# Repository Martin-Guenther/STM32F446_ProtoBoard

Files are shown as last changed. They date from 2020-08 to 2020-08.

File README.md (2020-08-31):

# STM32F446_ProtoBoard
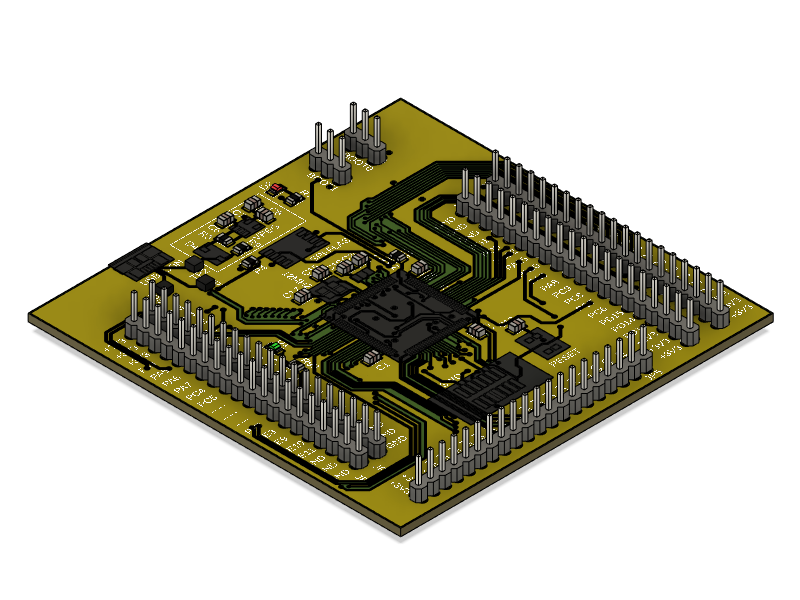
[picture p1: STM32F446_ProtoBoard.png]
STM32F446_ProtoBoard

  
A minimalist board with an STM32F446 microcontroller that can be used for prototypes. Most pins of the chip are routed to headers. It is powered over a USB connector and can also act as a USB device. It has SPI flash memory included and must be programmed via SWD.

### License
This is Open-Source-Hardware released under the GNU GPL license.

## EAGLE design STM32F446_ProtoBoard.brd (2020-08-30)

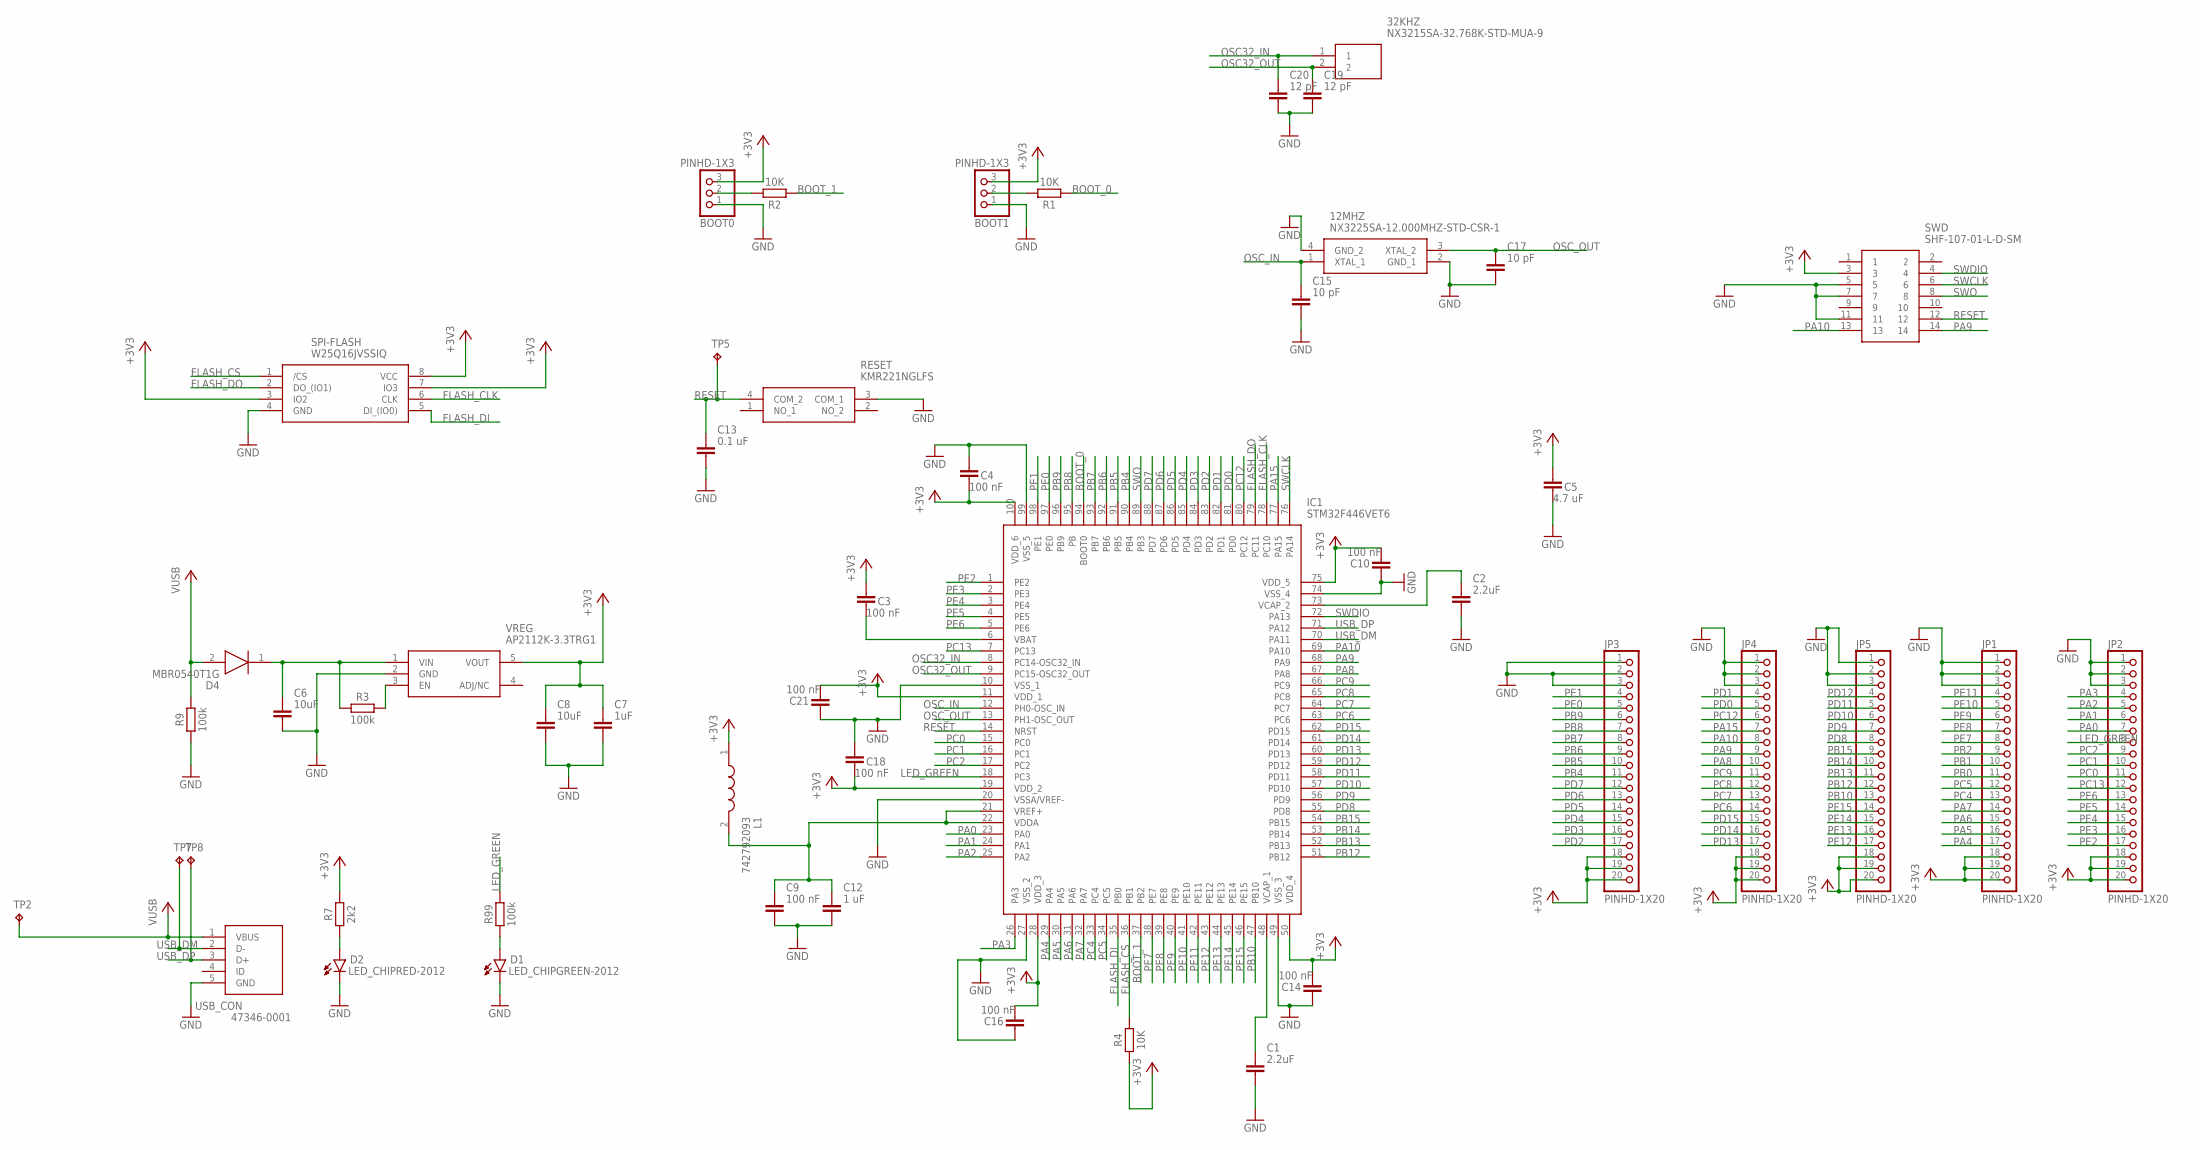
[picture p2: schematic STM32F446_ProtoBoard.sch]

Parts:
12MHZ: NX3225SA-12.000MHZ-STD-CSR-1; NX3225SA12000MHZSTDCSR1
32KHZ: NX3215SA-32.768K-STD-MUA-9; NX3215SA
BOOT0, BOOT1: PINHD-1X3; 1X03
C1, C2: 2.2uF; CAPC2012X110
C3, C4, C9, C10, C14, C16, C18, C21: 100 nF; CAPC2012X110
C5: 4.7 uF; CAPC2012X110
C6, C8: 10uF; CAPC2012X110
C7: 1uF; CAPC2012X110
C12: 1 uF; CAPC2012X110
C13: 0.1 uF; CAPC2012X110
C15, C17: 10 pF; CAPC2012X110
C19, C20: 12 pF; CAPC2012X110
D1: LED_CHIPGREEN-2012; LEDC2012X110N_G
D2: LED_CHIPRED-2012; LEDC2012X110N_R
D4: MBR0540T1G; SOD3716X135N
IC1: STM32F446VET6; QFP50P1600X1600X160-100N
JP1, JP2, JP3, JP4, JP5: PINHD-1X20; 1X20
L1: 742792093; CAPC2012X110N
R1, R2, R4: 10K; RESC2012X65
R3, R9, R99: 100k; RESC2012X65
R7: 2k2; RESC2012X65
RESET: KMR221NGLFS
SPI-FLASH: W25Q16JVSSIQ; SOIC127P790X216-8N
SWD: SHF-107-01-L-D-SM; SHF-107-01-X-D-SM
TP2, TP5, TP7, TP8: TPTP20R; TP20R
USB_CON: 47346-0001
VREG: AP2112K-3.3TRG1; SOT95P282X130-5N

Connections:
+3V3: BOOT0.3, BOOT1.3, C3.1, C4.2, C5.1, C7.1, C8.1, C10.2, C14.2, C16.2, C18.2, C21.2, IC1.11 (VDD_1), IC1.19 (VDD_2), IC1.28 (VDD_3), IC1.50 (VDD_4), IC1.75 (VDD_5), IC1.100 (VDD_6), JP1.18, JP1.19, JP1.20, JP2.18, JP2.19, JP2.20, JP3.18, JP3.19, JP3.20, JP4.18, JP4.19, JP4.20, JP5.18, JP5.19, JP5.20, L1.1, R4.1, R7.2, SPI-FLASH.3 (IO2), SPI-FLASH.7 (IO3), SPI-FLASH.8 (VCC), SWD.3, VREG.5 (VOUT)
+5V: D4.2 (A), R9.2, TP2.TP, USB_CON.1 (VBUS)
BOOT_0: IC1.94 (BOOT0), R1.1
BOOT_1: IC1.37 (PB2), R2.1
FLASH_CLK: IC1.78 (PC10), SPI-FLASH.6 (CLK)
FLASH_CS: IC1.36 (PB1), R4.2, SPI-FLASH.1 (/CS)
FLASH_DI: IC1.35 (PB0), SPI-FLASH.5 (DI_(IO0))
FLASH_DO: IC1.79 (PC11), SPI-FLASH.2 (DO_(IO1))
GND: 12MHZ.2 (GND_1), 12MHZ.4 (GND_2), BOOT0.1, BOOT1.1, C1.2, C2.2, C4.1, C5.2, C6.2, C7.2, C8.2, C9.2, C10.1, C12.2, C13.2, C14.1, C15.2, C16.1, C17.2, C18.1, C19.2, C20.2, C21.1, D1.1 (C), D2.1 (C), IC1.10 (VSS_1), IC1.20 (VSSA/VREF-), IC1.27 (VSS_2), IC1.49 (VSS_3), IC1.74 (VSS_4), IC1.99 (VSS_5), JP1.1, JP1.2, JP1.3, JP2.1, JP2.2, JP2.3, JP3.1, JP3.2, JP3.3, JP4.1, JP4.2, JP4.3, JP5.1, JP5.2, JP5.3, R9.1, RESET.3 (COM_1), SPI-FLASH.4 (GND), SWD.5, SWD.7, SWD.11, USB_CON.5 (GND), VREG.2 (GND)
LED_GREEN: IC1.18 (PC3), JP2.8, R99.2
unnamed: C6.1, D4.1 (K), R3.1, VREG.1 (VIN)
unnamed: R3.2, VREG.3 (EN)
unnamed: D2.2 (A), R7.1
unnamed: D1.2 (A), R99.1
unnamed: C1.1, IC1.48 (VCAP_1)
unnamed: C3.2, IC1.6 (VBAT)
unnamed: BOOT1.2, R1.2
unnamed: C2.1, IC1.73 (VCAP_2)
unnamed: BOOT0.2, R2.2
unnamed: C9.1, C12.1, IC1.21 (VREF+), IC1.22 (VDDA), L1.2
OSC32_IN: 32KHZ.1, C20.1, IC1.8 (PC14-OSC32_IN)
OSC32_OUT: 32KHZ.2, C19.1, IC1.9 (PC15-OSC32_OUT)
OSC_IN: 12MHZ.1 (XTAL_1), C15.1, IC1.12 (PH0-OSC_IN)
OSC_OUT: 12MHZ.3 (XTAL_2), C17.1, IC1.13 (PH1-OSC_OUT)
PA0: IC1.23 (PA0), JP2.7
PA1: IC1.24 (PA1), JP2.6
PA2: IC1.25 (PA2), JP2.5
PA3: IC1.26 (PA3), JP2.4
PA4: IC1.29 (PA4), JP1.17
PA5: IC1.30 (PA5), JP1.16
PA6: IC1.31 (PA6), JP1.15
PA7: IC1.32 (PA7), JP1.14
PA8: IC1.67 (PA8), JP4.10
PA9: IC1.68 (PA9), JP4.9, SWD.14
PA10: IC1.69 (PA10), JP4.8, SWD.13
PA15: IC1.77 (PA15), JP4.7
PB0: JP1.11
PB1: JP1.10
PB2: JP1.9
PB4: IC1.90 (PB4), JP3.11
PB5: IC1.91 (PB5), JP3.10
PB6: IC1.92 (PB6), JP3.9
PB7: IC1.93 (PB7), JP3.8
PB8: IC1.95 (PB), JP3.7
PB9: IC1.96 (PB9), JP3.6
PB10: IC1.47 (PB10), JP5.13
PB12: IC1.51 (PB12), JP5.12
PB13: IC1.52 (PB13), JP5.11
PB14: IC1.53 (PB14), JP5.10
PB15: IC1.54 (PB15), JP5.9
PC0: IC1.15 (PC0), JP2.11
PC1: IC1.16 (PC1), JP2.10
PC2: IC1.17 (PC2), JP2.9
PC4: IC1.33 (PC4), JP1.13
PC5: IC1.34 (PC5), JP1.12
PC6: IC1.63 (PC6), JP4.14
PC7: IC1.64 (PC7), JP4.13
PC8: IC1.65 (PC8), JP4.12
PC9: IC1.66 (PC9), JP4.11
PC12: IC1.80 (PC12), JP4.6
PC13: IC1.7 (PC13), JP2.12
PD0: IC1.81 (PD0), JP4.5
PD1: IC1.82 (PD1), JP4.4
PD2: IC1.83 (PD2), JP3.17
PD3: IC1.84 (PD3), JP3.16
PD4: IC1.85 (PD4), JP3.15
PD5: IC1.86 (PD5), JP3.14
PD6: IC1.87 (PD6), JP3.13
PD7: IC1.88 (PD7), JP3.12
PD8: IC1.55 (PD8), JP5.8
PD9: IC1.56 (PD9), JP5.7
PD10: IC1.57 (PD10), JP5.6
PD11: IC1.58 (PD11), JP5.5
PD12: IC1.59 (PD12), JP5.4
PD13: IC1.60 (PD13), JP4.17
PD14: IC1.61 (PD14), JP4.16
PD15: IC1.62 (PD15), JP4.15
PE0: IC1.97 (PE0), JP3.5
PE1: IC1.98 (PE1), JP3.4
PE2: IC1.1 (PE2), JP2.17
PE3: IC1.2 (PE3), JP2.16
PE4: IC1.3 (PE4), JP2.15
PE5: IC1.4 (PE5), JP2.14
PE6: IC1.5 (PE6), JP2.13
PE7: IC1.38 (PE7), JP1.8
PE8: IC1.39 (PE8), JP1.7
PE9: IC1.40 (PE9), JP1.6
PE10: IC1.41 (PE10), JP1.5
PE11: IC1.42 (PE11), JP1.4
PE12: IC1.43 (PE12), JP5.17
PE13: IC1.44 (PE13), JP5.16
PE14: IC1.45 (PE14), JP5.15
PE15: IC1.46 (PE15), JP5.14
RESET: C13.1, IC1.14 (NRST), RESET.4 (COM_2), SWD.12, TP5.TP
SWCLK: IC1.76 (PA14), SWD.6
SWDIO: IC1.72 (PA13), SWD.4
SWO: IC1.89 (PB3), SWD.8
USB_DM: IC1.70 (PA11), TP7.TP, USB_CON.2 (D-)
USB_DP: IC1.71 (PA12), TP8.TP, USB_CON.3 (D+)

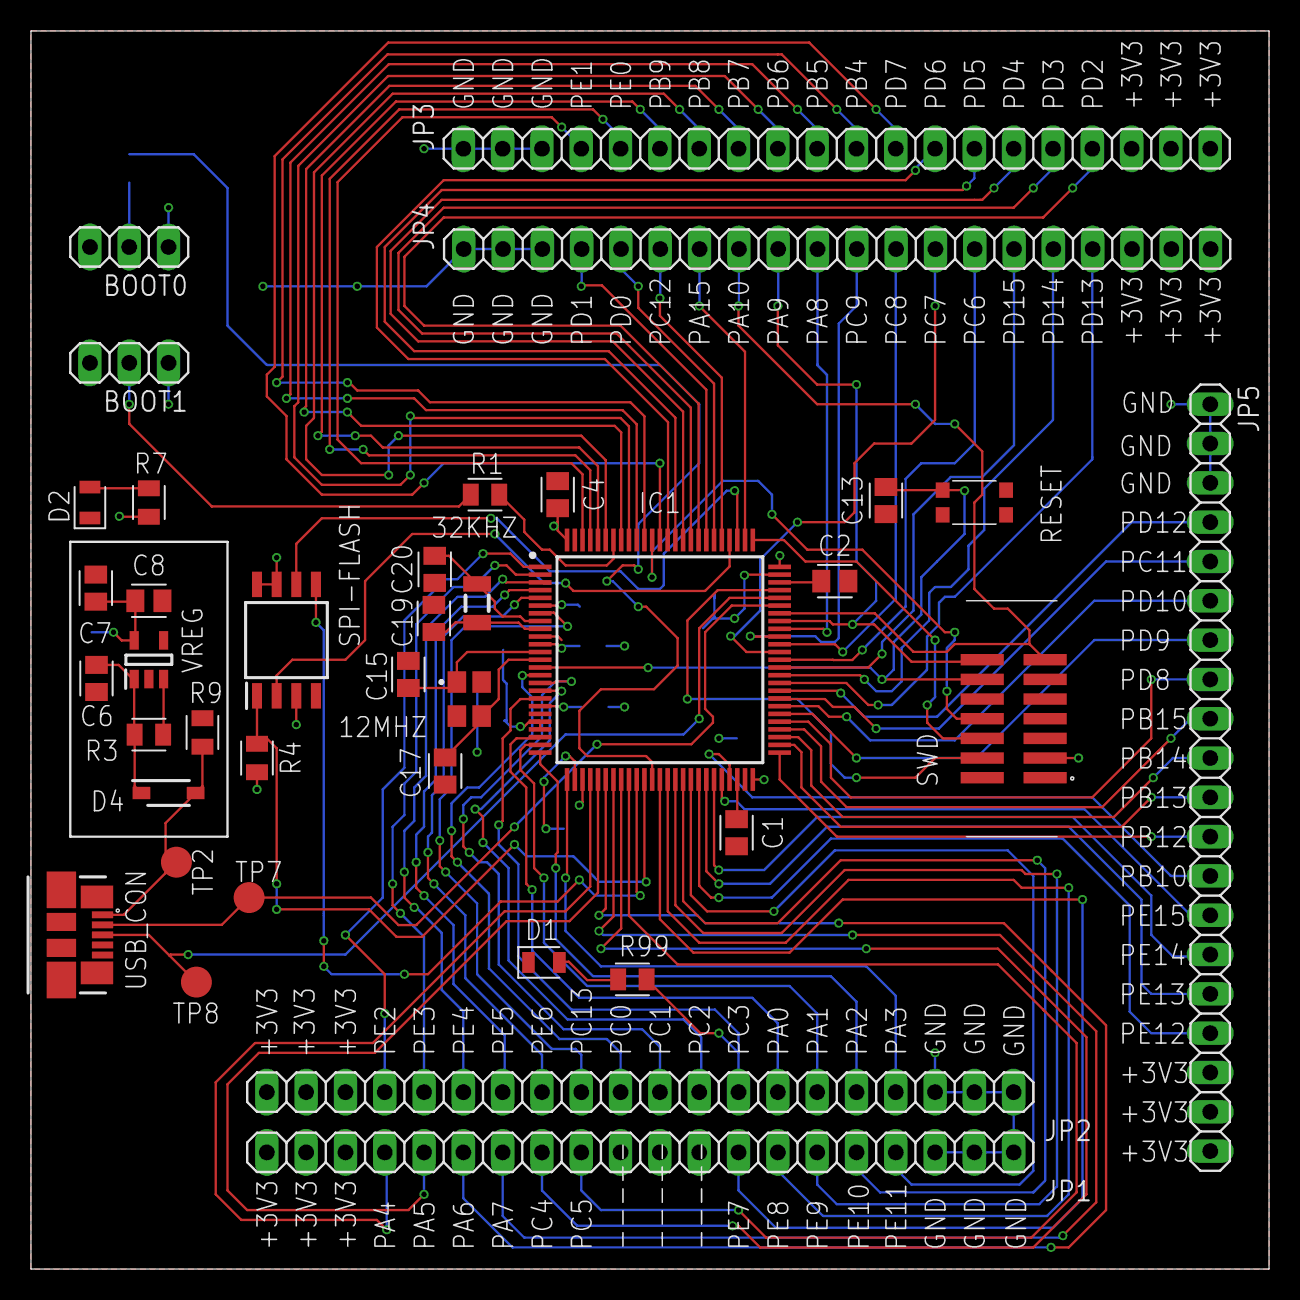
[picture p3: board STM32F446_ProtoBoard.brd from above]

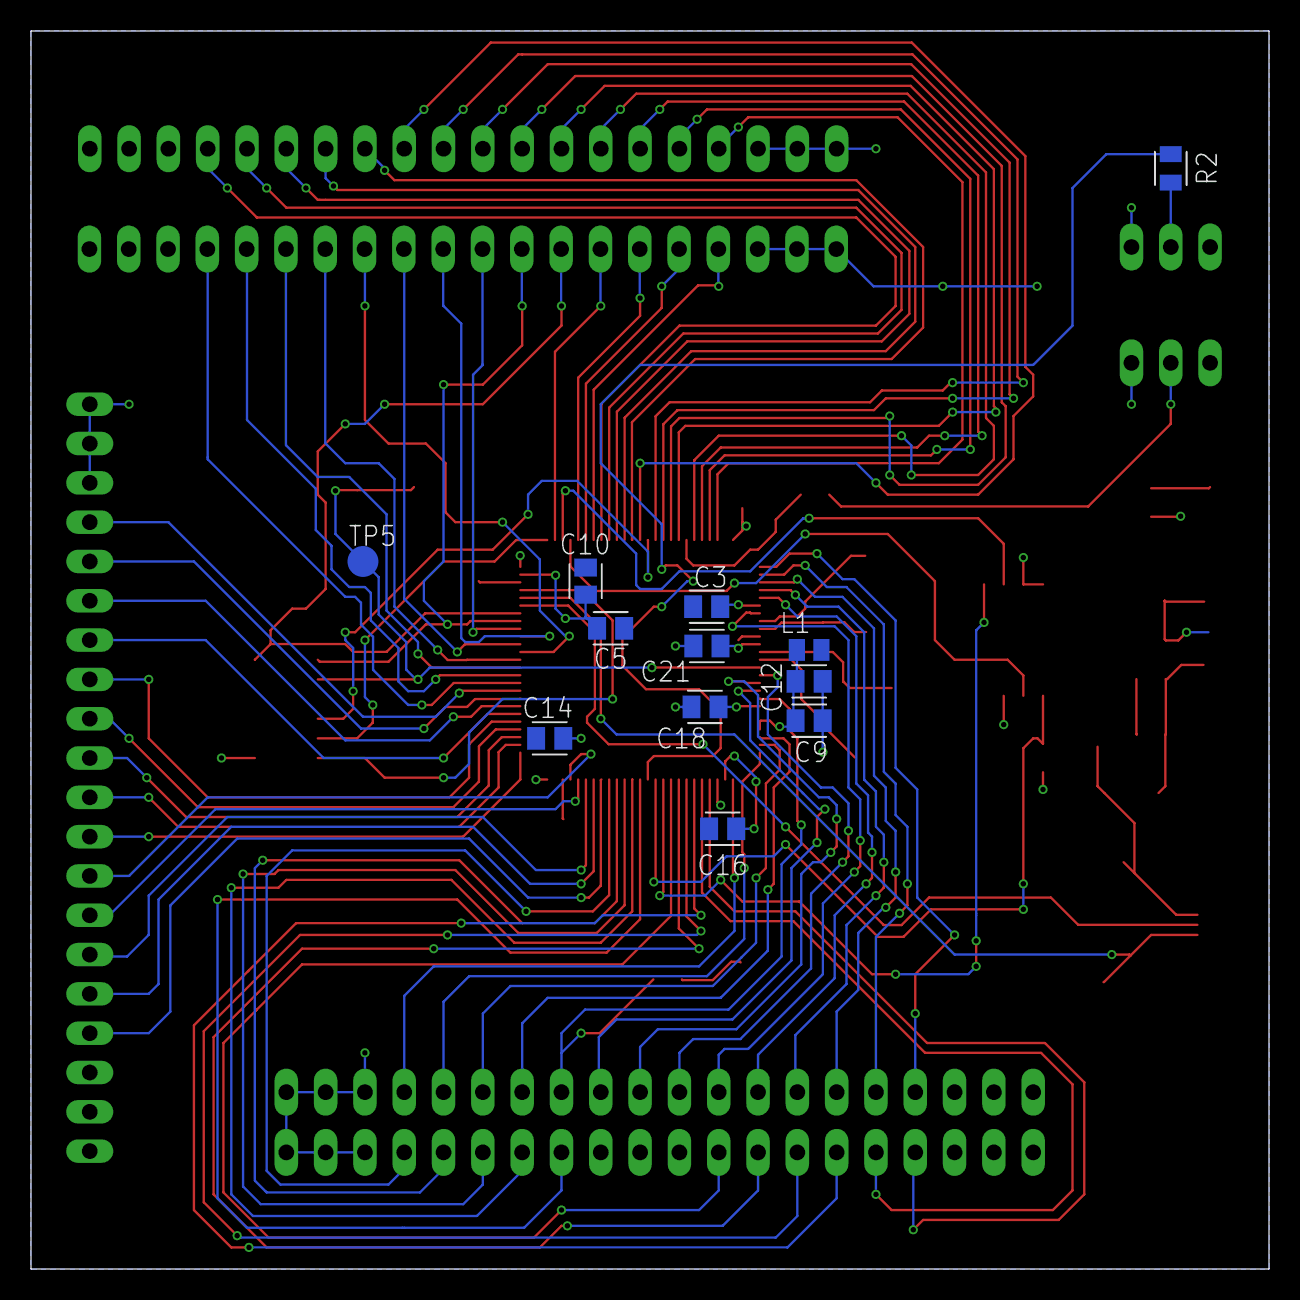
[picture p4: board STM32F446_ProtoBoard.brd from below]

Board: 2 copper layers, 80.0 x 80.0 mm, 50 parts (12 on the bottom side), 96 nets.
